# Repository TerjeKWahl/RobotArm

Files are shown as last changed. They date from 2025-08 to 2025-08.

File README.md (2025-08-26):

# RobotArm

Humanoid robot arm with 6 DoF and a gripper, built mostly in Lego, controllable from VR and (todo) with AI to make it autonomous.

This repository contains the following project parts in these folders:
- `EmbeddedControllers` Robot arm embedded controllers
  - `ControllerLowerArm` Lego Technic Hub 1 controller (lower arm) using Pybricks
  - `ControllerShoulder` Lego Technic Hub 2 controller (shoulder) using Pybricks
  - `ControllerGripper` Controller for the gripper using Arduino
- `RobotArmController` Main controller program in Python, executed on a PC to 
  - control the robot arm using inverse kinematics,
  - communicate with the Lego Technic Hubs and Arduino controllers,
  - communicate with any connected VR app,
  - (todo) gather images from vision camera,
  - (todo) do AI raw data collection and
  - (todo) do AI inference
- `VR` Meta Quest 3 VR app to remote control the robot arm and (todo) record AI training data
- `AI` TODO: AI stuff: Training and inference
- `Mechanics` 3D files for custom made mechanical parts
  - `GripperForMicroServo` 3D files for robot gripper
  - `LegoTechnicHubWireInset` 3D file for modifying Lego Technic Hub to be driven by a power adapter in stead of batteries
  - `VrGripper` 3D file for the virtual representation of the gripper in the VR app

These components communicate using well defined communication APIs. Please see the `Docs` folder for more information.

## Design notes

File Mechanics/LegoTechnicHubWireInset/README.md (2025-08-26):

# Lego Technic Hub wire inset

Based on the "9V Battery Adapter for Lego Powered Up/Control+ Technic Hub"
by 2GodBDGlory (Cole Johnstone). The original work can be found here: 
https://www.thingiverse.com/thing:6434892

Modified using FreeCAD to be able to hold 0.7 mm wires over the battery contact points, so that a 9V power adapter can be used to continuously power the Lego Technic Hub.

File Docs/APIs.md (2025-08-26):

# APIs used for communicating between components

The following APIs are used:
- API for communication between PC application and Lego Technic Hub 1 (lower arm) or Lego Technic 
  Hub 2 (shoulder) or Arduino (gripper)
- API for communication between PC application and VR app

## API for communication between PC application and Lego Technic Hub 1 or 2, and Arduino:

We want to keep payloads short when communication with Lego Hubs, because of Bluetooth packet limitations (source:
https://github.com/pybricks/technical-info/blob/master/pybricks-ble-broadcast-observe.md). Because of this, a
proprietary binary communication protocol is used. Angles are in degrees. 
The numbering in the two lists below represent byte numbers.

### Message from PC to Lego Technic Hub 1 or 2 or Arduino (the same data is sent to all):

1.  Prefix "T"
2.  Prefix "W"
3.  API version, 1
4.  int8, requested movement mode:  
    - 1 = move all joints as fast as possible (for continuous tracking)
    - 2 = move to target with smooth acceleration and deceleration (run to target)
    - 3 = calibration mode
    - 4 = return to standard/zero angles, and exit
5.  int8, desired angle for gripper
6.  int8, desired angle for wrist  
7.  int8, desired angle for underarm 
8.  int8, desired angle for elbow   
9.  int8, desired angle for overarm  
10. int8, desired angle for shoulder_out  
11. int8, desired angle for shoulder_forward 
12. int8, last known angle for gripper
13. int8, last known angle for wrist  
14. int8, last known angle for underarm 
15. int8, last known angle for elbow   
16. int8, last known angle for overarm  
17. int8, last known angle for shoulder_out  
18. int8, last known angle for shoulder_forward 

### Message from Lego Technic Hub 1 or 2 or Arduino to PC:

1.  Prefix "T"
2.  Prefix "W"
3.  API version, 1
4.  int8, information source:  
    - 10 = Lego Technic Hub 1 (lower arm), ignore shoulder and gripper joint values
    - 11 = Lego Technic Hub 2 (shoulder), ignore lower arm and gripper joint values
    - 12 = Arduino (gripper), ignore shoulder and lower arm joint values
5.  int8, error code - 0 means no error
6.  int8, current angle for gripper (or -128 if unknown)
7.  int8, current angle for wrist (or -128 if unknown)
8.  int8, current angle for underarm (or -128 if unknown)
9.  int8, current angle for elbow (or -128 if unknown)
10. int8, current angle for overarm (or -128 if unknown)
11. int8, current angle for shoulder_out (or -128 if unknown)
12. int8, current angle for shoulder_forward (or -128 if unknown)

## API for communication between PC application and VR app

To make communication efficient on a LAN, we use UDP packets and make sure the payload is short enough 
to fit within one WiFi/Ethernet UDP package (around 1400 bytes).

When talking about position and rotation in messages to and from the VR app, we use the VR/Unity coordinate
system (x-right, y-up, z-forward), and not the robot arm's coordinate system (x-forward, y-left, z-up).

VR app should send a UDP package to the PC every second frame (around 30-36 times per second).

The PC should send a UDP package to the VR app around 30-50 times per second.

16 bit numbers are sent big-endian (MSB first, LSB last). Distances are in mm. Angles are in degrees. 

### Message from VR to PC:

1.  Prefix "T"
2.  Prefix "K"
3.  Prefix "W"
4.  API version, 1
5.  int8, information source:  
    - 20 = VR app
6.  int8, desired gripper angle, in degrees
7.  int8, desired recording status: 0=off, 1=on
8.  (Reserved for future use, extra byte to avoid bugs due to struct packing.)
9.  Bytes number 9 to 136: 16 double floating point numbers, representing the 4 x 4 matrix 
    describing the position and rotation of the VR gripper.
    16 doubles * 8 bytes/double = 128 bytes.
    The numbers are row first, so the first 4 numbers represent the first row, etc.

### Message from PC to VR:

1.  Prefix "T"
2.  Prefix "K"
3.  Prefix "W"
4.  API version, 1
5.  int8, information source:  
    - 21 = PC app
6.  (Reserved for future use, extra byte to avoid bugs due to struct packing.)
7.  (Reserved for future use, extra byte to avoid bugs due to struct packing.)
8.  (Reserved for future use, extra byte to avoid bugs due to struct packing.)
9.  Bytes number 9 to 136: 16 double floating point numbers, representing the 4 x 4 matrix 
    describing the last known position and rotation of the physical robot arm's gripper.
    16 doubles * 8 bytes/double = 128 bytes.
    The numbers are row first, so the first 4 numbers represent the first row, etc.

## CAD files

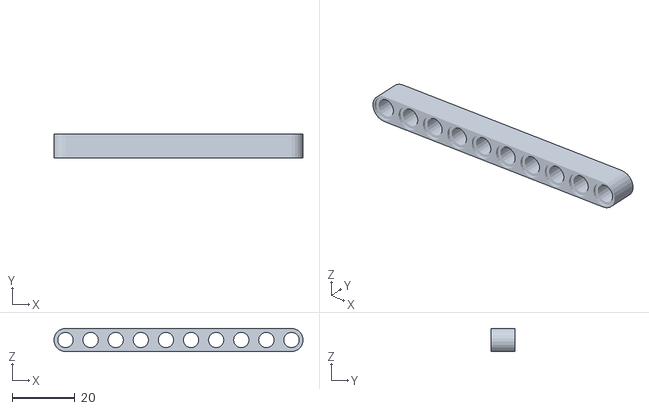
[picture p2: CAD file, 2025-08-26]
Mechanics/GripperForMicroServo/10M_Beam_Lego.stl
79.3 x 7.80 x 7.40

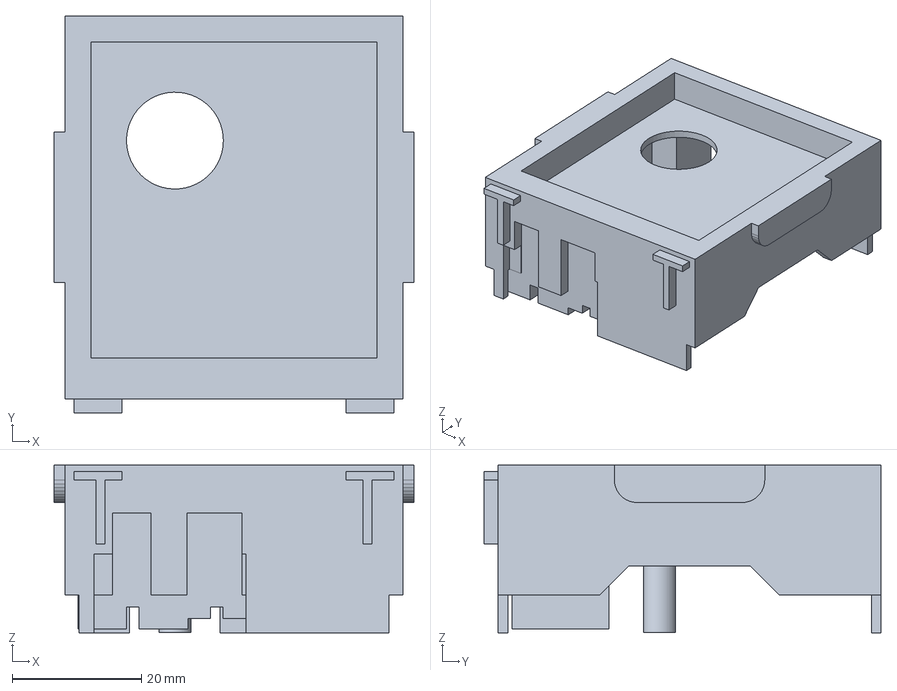
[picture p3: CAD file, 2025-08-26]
Mechanics/LegoTechnicHubWireInset/Lego Technic Hub wire inset.FCStd
55.7 x 61.5 x 26.0 mm

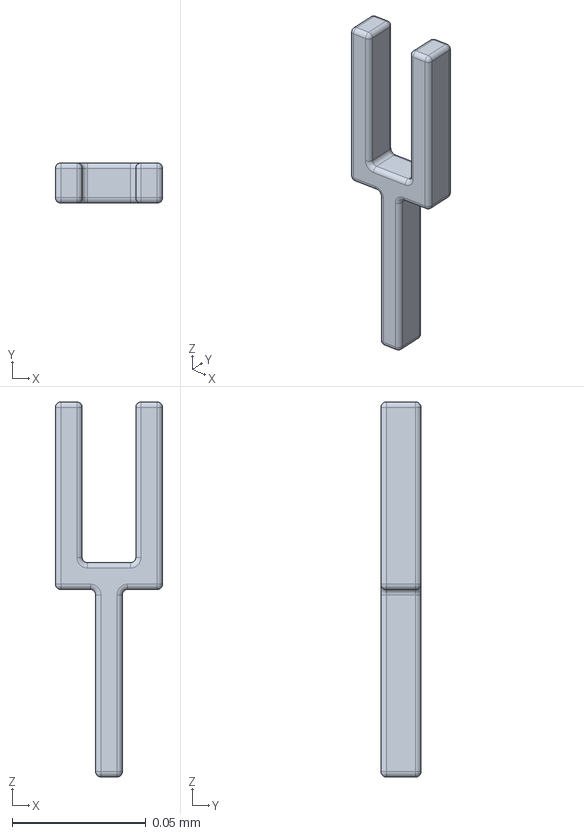
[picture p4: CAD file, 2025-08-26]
Mechanics/VrGripper/VrGripper.FCStd
0.04 x 0.015 x 0.14 mm

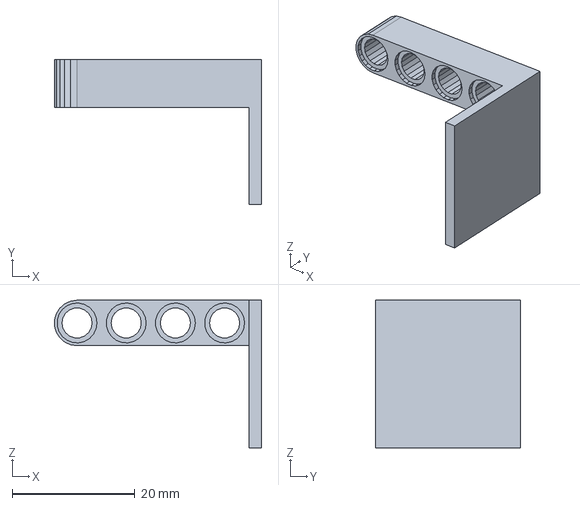
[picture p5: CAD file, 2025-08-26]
Mechanics/GripperForMicroServo/GripperForMicroServo.FCStd
33.7 x 23.6 x 24.0 mm

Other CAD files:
VR/RobotArmRemoteController/Assets/VrGripper.obj
Mechanics/LegoTechnicHubWireInset/Lego Technic Hub wire inset - 1.1.step
Mechanics/LegoTechnicHubWireInset/9V_Powered_Up_Adapter_v3.stl
Mechanics/VrGripper/VrGripper.obj

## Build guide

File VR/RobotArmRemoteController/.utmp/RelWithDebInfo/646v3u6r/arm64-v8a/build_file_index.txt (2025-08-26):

C:\dev\RobotArm\VR\RobotArmRemoteController\Library\Bee\Android\Prj\IL2CPP\Gradle\unityLibrary\src\main\cpp\CMakeLists.txt
C:\dev\RobotArm\VR\RobotArmRemoteController\Library\Bee\Android\Prj\IL2CPP\Gradle\unityLibrary\src\main\cpp\GameActivity\CMakeLists.txt

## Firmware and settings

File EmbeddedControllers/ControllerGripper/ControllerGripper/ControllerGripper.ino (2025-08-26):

/**
 * Controlling a servo using an Arduino Uno R4 WiFi. 
 * 
 * Servo used: 
 * Geekservo 2KG Mini Servo 360 Degree
 * ------------
 * Weight: 20g
 * Operating voltage: 4.8V - 6.0V
 * Operating speed (at no load) 0.14±0.01sec/60° 0.12±0.01sec/60°
 * Running current (at no load) 70±20mA 90±20mA
 * Stall torque (at locked) 1.8±0.2kg-cm 2±0.2kg-cm
 * Stall current (at locked) 0.8±0.1A 0.9±0.1A
 * Neutral position:1500μsec
 * Dead band width: ≤4μsec
 * Rotating direction: counter Clockwise (1500→500μsec)
 * Pulse width range: 500→2500 μsec
 * Maximum travel 360°(500→2500 μsec)
 *
 * Wiring:
 * Brown: GND
 * Red: VCC (4.8 ~ 6.6v)
 * Orange: PWM Signal
 */

#include "Arduino_LED_Matrix.h"
#include <Servo.h>
#include <WiFiS3.h>
#include "WifiSecrets.h"    // Please enter your sensitive data into WifiSecrets.h, by defining SECRET_SSID and SECRET_PASS there.
#include "Configuration.h"
#include "RobotMessageManager.h"

const int16_t SERVO_PIN = 9;
const uint32_t MAX_WAIT_TIME_FOR_SERIAL_MS = 3000; // Maximum wait time for serial connection to start working on startup, in milliseconds

Servo gripperServo; 

int wifiStatus = WL_IDLE_STATUS;
char ssid[] = SECRET_SSID;  // your network SSID (name)
char pass[] = SECRET_PASS;  // your network password (use for WPA, or use as key for WEP)
char receiveBuffer[256]; //buffer to hold incoming packet
char sendBuffer[256] = "TKW"; // a string to send back
WiFiUDP udp;

ArduinoLEDMatrix matrix;
uint32_t frame[] = { 0x00000000, 0x00000000, 0x00000000 }; // 1-bit display buffer for the 12 x 8 pixel display


void setup() 
{
    Serial.begin(115200);

    matrix.begin();
    matrix.loadFrame(LEDMATRIX_CHIP); // Boot screen
    
    gripperServo.attach(SERVO_PIN);
    gripperServo.writeMicroseconds(getServoUsFromDegrees(GRIPPER_ANGLE_MAX_DEG));

    while (!Serial && (millis() < MAX_WAIT_TIME_FOR_SERIAL_MS)) {
        ; // Wait for serial port to connect.
    }
    while (millis() < MAX_WAIT_TIME_FOR_SERIAL_MS) 
    {
        delay(10); // Give some time for the serial connection to stabilize, if it was plugged in.
    }

    Serial.println("\nControllerGripper started!");

    matrix.loadFrame(LEDMATRIX_CLOUD_WIFI);
    connectToWifi();

    Serial.println("\nStarting connection to server...");
    udp.begin(ARDUINO_UDP_PORT);

    Serial.println("Setup complete, ready to control the gripper.");
    matrix.loadFrame(LEDMATRIX_HEART_BIG);
    delay(500);
    matrix.loadFrame(LEDMATRIX_EMOJI_HAPPY);
    delay(500);
}

  
void loop() 
{

    while(true)
    {
        // Demo mode
        uint32_t demoDurationWantedMs = 0; //20000; // Duration of demo mode before going into normal remote control function. Set to 0 to skip demo mode.
        uint32_t currentTimeMs = millis();
        uint32_t demoStartMs = currentTimeMs;
        int16_t servoPositionDegrees = 0;
        if (demoDurationWantedMs > 0)
        {
            Serial.println("Starting demo mode");
            while (currentTimeMs - demoStartMs < demoDurationWantedMs) {
                uint32_t timeInPeriod = (currentTimeMs - demoStartMs) % 10000; // 10 seconds cycle

                if (timeInPeriod < 2000) 
                {
                    servoPositionDegrees = map(timeInPeriod, 0, 2000, GRIPPER_ANGLE_MIN_DEG, GRIPPER_ANGLE_MAX_DEG);
                } 
                else if (timeInPeriod < 4000) 
                {
                    servoPositionDegrees = map(timeInPeriod, 2000, 4000, GRIPPER_ANGLE_MAX_DEG, GRIPPER_ANGLE_MIN_DEG);
                } 
                else if (timeInPeriod < 5000) 
                {
                    servoPositionDegrees = GRIPPER_ANGLE_MIN_DEG;
                } 
                else if (timeInPeriod < 6000) 
                {
                    servoPositionDegrees = map(timeInPeriod, 5000, 6000, GRIPPER_ANGLE_MIN_DEG, GRIPPER_ANGLE_MAX_DEG);
                } 
                else if (timeInPeriod < 7000) 
                {
                    servoPositionDegrees = map(timeInPeriod, 6000, 7000, GRIPPER_ANGLE_MAX_DEG, GRIPPER_ANGLE_MIN_DEG);
                } 
                else if (timeInPeriod < 7500) 
                {
                    servoPositionDegrees = map(timeInPeriod, 7000, 7500, GRIPPER_ANGLE_MIN_DEG, GRIPPER_ANGLE_MAX_DEG);
                } 
                else if (timeInPeriod < 8000) 
                {
                    servoPositionDegrees = map(timeInPeriod, 7500, 8000, GRIPPER_ANGLE_MAX_DEG, GRIPPER_ANGLE_MIN_DEG);
                } 
                else 
                {
                    servoPositionDegrees = GRIPPER_ANGLE_MIN_DEG;
                }

                moveGripper(servoPositionDegrees);

                currentTimeMs = millis(); // Update current time for next iteration of the while loop
            }
            Serial.println("Demo mode finished, entering normal operation mode.");
        }


        // Normal operation
        while(true) // Outer loop to handle errors and reconnects
        {
            int16_t servoPositionDegrees = GRIPPER_ANGLE_MAX_DEG; // Start with fully opened gripper
            moveGripper(servoPositionDegrees);
            int32_t lastSendTimeMs = 0;

            while(true) // Inner loop to handle incoming UDP messages and send updates
            { 
                // Check if WiFi is still connected (WiFi.status() == WL_CONNECTED)
                if (WiFi.status() != WL_CONNECTED) {
                    Serial.println("WiFi disconnected!");
                    break; // Exit the inner loop to reconnect
                }

                // Update the gripper position based on any incoming UDP messages
                int packetSize = udp.parsePacket();
                if (packetSize) 
                {
                    uint8_t receiveBuffer[REC_MSG_LENGTH];
                    if (packetSize > REC_MSG_LENGTH) 
                    {
                        Serial.println("Packet size exceeds buffer size. Ignoring it.");
                        udp.flush();
                    }
                    else
                    {
                        int len = udp.read(receiveBuffer, REC_MSG_LENGTH);
                        if (len == 0) 
                        {
                            Serial.println("Failed to read UDP packet.");
                            break; // Exit the inner loop to reconnect
                        }
                        // Parse the incoming message
                        bool isSuccessful = false;
                        MessageFromPcToController incomingMessage = parseMessageFromPcToController(receiveBuffer, len, &isSuccessful);
                        if (!isSuccessful) 
                        {
                            Serial.println("Failed to parse incoming message.");
                            break; // Exit the inner loop to reconnect
                        }
                        servoPositionDegrees = incomingMessage.desiredAngles.gripper;
                        if (incomingMessage.movementMode == RETURN_TO_ZERO) 
                        {
                            servoPositionDegrees = GRIPPER_ANGLE_MAX_DEG; // Full opening of the gripper is the default position ("zero")
                        }
                        moveGripper(servoPositionDegrees);

                        /*
                        // Debug output is slow (synchronous) and the lines below causes visible lag for the gripper, so only print if you need to debug
                        Serial.print("Received packet of size ");
                        Serial.print(packetSize);
                        Serial.print(" from ");
                        IPAddress remoteIp = udp.remoteIP();
                        Serial.print(remoteIp);
                        Serial.print(", port ");
                        Serial.println(udp.remotePort());
                        Serial.print("New desired gripper angle: ");
                        Serial.println(servoPositionDegrees);
                        */
                    }
                }


                // Send UDP message to the PC every SEND_PERIOD_MS milliseconds
                uint32_t currentTimeMs = millis();
                if (currentTimeMs - lastSendTimeMs >= SEND_PERIOD_MS) {
                    lastSendTimeMs = currentTimeMs;
                    udp.beginPacket(PC_IP_ADDRESS, ARDUINO_UDP_PORT);
                    uint8_t sendBuffer[SEND_MSG_LENGTH];
                    createMessageFromControllerToPc(servoPositionDegrees, sendBuffer);
                    udp.write(sendBuffer, SEND_MSG_LENGTH);
                    int16_t isSentSuccessfully = udp.endPacket();
                    if (!isSentSuccessfully) {
                        Serial.println("Failed to send UDP packet!");
                        break; // Exit the inner loop to reconnect
                    }
                }
            }

            // Disconnect and reconnect to WiFi
            Serial.println("Disconnecting from WiFi, and attempting reconnect...");
            udp.flush();
            udp.stop();
            WiFi.end();
            connectToWifi();
        }


    }
}


/**
 * Moves the gripper servo to the specified position and updates the LED matrix display.
 * 
 * @param targetDegrees: Target position for the gripper servo in degrees
 */
void moveGripper(int16_t targetDegrees) {
    gripperServo.writeMicroseconds(getServoUsFromDegrees(targetDegrees));
    updateFrame(frame, targetDegrees);
    matrix.loadFrame(frame);
}


/**
 * Updates the frame that represents the 1-bit display buffer for the 12 x 8 pixel display.
 * Lights up from 0 to 12 pixels on the first two rows, depending on the servoPositionDegrees that
 * is from GRIPPER_ANGLE_MIN_DEG to GRIPPER_ANGLE_MAX_DEG degrees.
 */
void updateFrame(uint32_t *frame, int servoPositionDegrees) 
{
    // Check for valid servo position by clipping it to the valid range
    if (servoPositionDegrees < GRIPPER_ANGLE_MIN_DEG) 
    {
        servoPositionDegrees = GRIPPER_ANGLE_MIN_DEG;
    } 
    else if (servoPositionDegrees > GRIPPER_ANGLE_MAX_DEG) 
    {
        servoPositionDegrees = GRIPPER_ANGLE_MAX_DEG;
    }
    // Could do some error checking here on the frame buffer, but hey this is a hobby project.

    // Clear the frame first (reset all bits except type "TW" in the middle of the display))
    frame[0] = 0b00000000000000000000000001110100;
    frame[1] = 0b01000010010101000010001010000010;
    frame[2] = 0b00101000000000000000000000000000;
    
    // Map servo position to number of pixels (0-12). 
    int numPixels = map(servoPositionDegrees, GRIPPER_ANGLE_MAX_DEG, GRIPPER_ANGLE_MIN_DEG, 0, 12);

    // Set pixels in first two rows
    for (int bitPosition = 0; bitPosition < numPixels; bitPosition++) {
        // Set pixel in first row (bits 31-20)
        frame[0] |= (1UL << (31 - bitPosition));
        // Set pixel in second row (bits 19-8)
        frame[0] |= (1UL << (19 - bitPosition));
    }
}


void connectToWifi() 
{
    Serial.println("Connecting to WiFi network...");

    // Check for the presence of the WiFi module:
    if (WiFi.status() == WL_NO_MODULE) {
        Serial.println("Communication with WiFi module failed!");
        // Don't continue
        while (true);
    }

    String fv = WiFi.firmwareVersion();
    if (fv < WIFI_FIRMWARE_LATEST_VERSION) {
        Serial.println("(Please consider upgrading the WiFi module firmware.)");
    }

    // Attempt to connect to WiFi network:
    Serial.print("Attempting to connect to SSID: ");
    Serial.println(ssid);
    // Connect to WPA/WPA2 network. Change this line if using open or WEP network:
    wifiStatus = WiFi.begin(ssid, pass);
    // wait up to 10 seconds for connection:
    int secondsWaited = 0;
    while (wifiStatus != WL_CONNECTED && secondsWaited < 20) 
    {
        Serial.println("Waiting for connection...");
        delay(1000);
        wifiStatus = WiFi.status();
        secondsWaited++;
    }
    IPAddress ip = WiFi.localIP();
    while ((uint32_t)ip == 0 && secondsWaited < 20) 
    {
        Serial.println("Waiting for IP address...");
        delay(1000);
        ip = WiFi.localIP();
        secondsWaited++;
    }
    Serial.println("Connected to WiFi!");
    printWifiStatus();
}


void printWifiStatus() {
    // print the SSID of the network you're attached to:
    Serial.print("SSID: ");
    Serial.println(WiFi.SSID());

    // print your board's IP address:
    IPAddress ip = WiFi.localIP();
    Serial.print("IP Address: ");
    Serial.println(ip);

    // print the received signal strength:
    long rssi = WiFi.RSSI();
    Serial.print("signal strength (RSSI):");
    Serial.print(rssi);
    Serial.println(" dBm");
}


/**
 * Converts servo position in degrees to microseconds for PWM control.
 * Standard servo control uses pulse widths between 500-2500 microseconds.
 * 
 * This function is customized to fit with the servo and physical robot arm being used,
 * to match the minimum and maximum angles to the physical robot arm.
 * 
 * @param degrees: Servo position in degrees
 * @return: Pulse width in microseconds
 */
uint16_t getServoUsFromDegrees(int16_t degrees) {
    // Constrain degrees to valid servo range (0-180)
    if (degrees < GRIPPER_ANGLE_MIN_DEG) {
        degrees = GRIPPER_ANGLE_MIN_DEG;
    } else if (degrees > GRIPPER_ANGLE_MAX_DEG) {
        degrees = GRIPPER_ANGLE_MAX_DEG;
    }

    // Map degrees (GRIPPER_ANGLE_MIN_DEG-GRIPPER_ANGLE_MAX_DEG) to microseconds
    const int16_t US_MIN = 1500 + 25; // Don't squeeze too tightly
    const int16_t US_MAX = 1750; // 1500 + 5.55 per degree. So for 45 degrees it is 1500+250 = 1750
    const int16_t SPAN = GRIPPER_ANGLE_MAX_DEG - GRIPPER_ANGLE_MIN_DEG;
    return US_MIN + ((uint32_t)degrees * (US_MAX - US_MIN)) / SPAN;
}

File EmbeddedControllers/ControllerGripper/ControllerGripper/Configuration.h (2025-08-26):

#include <stdint.h>
#include "IPAddress.h"

// Please make a DHCP reservation on your router for this device and the PC, so that they 
// always get the same IP address that can be used to control the gripper.
const IPAddress PC_IP_ADDRESS = IPAddress( 192, 168, 0, 43 ); // IP address of the PC that controls the gripper
const uint16_t ARDUINO_UDP_PORT = 7507; // Port for UDP communication between Arduino and PC (both sending and receiving)

const uint8_t GRIPPER_ANGLE_MIN_DEG = 0;
const uint8_t GRIPPER_ANGLE_MAX_DEG = 45;

const int16_t SEND_PERIOD_MS = 100; // How often to send current gripper angle to the PC app

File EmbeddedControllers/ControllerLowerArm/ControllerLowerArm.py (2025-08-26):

"""
Controls the lower 4 axis on a robot arm (wrist, underarm twist, elbow, overarm twist), 
and communicates with a PC app.
Built using Pybricks (see pybricks.com for more info).
"""

from pybricks.hubs import TechnicHub
from pybricks.pupdevices import Motor
from pybricks.parameters import Button, Color, Direction, Port, Side, Stop
from pybricks.tools import wait, StopWatch
from usys import stdin, stdout
from uselect import poll, POLLIN
from micropython import kbd_intr
from RobotMessageBuilderEmbedded import JointAngles, MessageFromPCToController, \
     parse_message_from_PC_to_controller, create_message_from_controller_to_PC, \
     INFORMATION_SOURCE_HUB_1, REC_MSG_LENGTH, \
     MOVEMENT_MODE_MOVE_FAST, MOVEMENT_MODE_RUN_TO_TARGET, \
     MOVEMENT_MODE_CALIBRATION, MOVEMENT_MODE_RETURN_TO_ZERO_AND_EXIT

PRINT_DEBUG_INFO = False # Set to True to enable debug messages via printing to stdout. This will interfere with Bluetooth communication that also uses stdout!
SEND_PERIOD_MS = 20 # How often to send current angles to the PC app

is_continuous_tracking = False
hub = TechnicHub()
stopwatch = StopWatch()
stopwatch.resume()
receive_buffer = bytearray(REC_MSG_LENGTH)

# Motor definitions, including gearing ratios:
wrist    = a = Motor(Port.A, positive_direction=Direction.CLOCKWISE,        reset_angle=False, gears=[[20, 12], [ 1, 12], [12, 28]]) # Wrist up/down (as seen when right thumb is up)
underarm = b = Motor(Port.B, positive_direction=Direction.CLOCKWISE       , reset_angle=False, gears=[[ 8, 24], [12, 20], [ 8, 28]]) # Underarm twist
elbow    = c = Motor(Port.C, positive_direction=Direction.COUNTERCLOCKWISE, reset_angle=False, gears=[[ 1, 24], [20, 28]]) # Elbow
overarm  = d = Motor(Port.D, positive_direction=Direction.COUNTERCLOCKWISE, reset_angle=False, gears=[[ 8, 24], [12, 60]]) # Overarm twist

last_known_angles = JointAngles(set_all_unknown = True)
last_send_time = 0
last_receive_time = 0
desired_angle_wrist = 0
desired_angle_underarm = 0


def print_debug(string):
    if PRINT_DEBUG_INFO:
        print(string)



def get_compensations_for_angles(last_known_angles: JointAngles):
    """
    Calculates the compensations needed for the wrist and underarm angles based on the last known angles.
    """
    # Calculate the compensation of underarm due to elbow angle
    underarm_compensation = last_known_angles.elbow * 0.4 # (28/12) * (12/20) * (8/28)

    # Calculate the compensation of wrist due to underarm and elbow angles
    wrist_compensation_due_to_underarm = last_known_angles.underarm * 0.428571429 # (12/28)
    wrist_compensation_due_to_elbow = last_known_angles.elbow # * (28/12) * (12/28), which is 1
    wrist_compensation = wrist_compensation_due_to_underarm + wrist_compensation_due_to_elbow

    return wrist_compensation, underarm_compensation



def send_current_angles_to_pc(last_known_angles: JointAngles):
    """
    Reads current motor positions and sends them to PC via stdout.
    Updates the relevant values in last_known_angles.
    """
    # Update known angles from motor positions
    known_angle_wrist = wrist.angle()
    known_angle_underarm = underarm.angle()
    known_angle_elbow = elbow.angle()
    known_angle_overarm = overarm.angle()
    last_known_angles.wrist = known_angle_wrist
    last_known_angles.underarm = known_angle_underarm
    last_known_angles.elbow = known_angle_elbow
    last_known_angles.overarm = known_angle_overarm

    # Create JointAngles with only lower arm angles known
    # Subtract compensation of wrist and underarm to report in the same way the desired 
    # angle is used, to avoid the robot arm being unstable (wiggling)
    wrist_compensation, underarm_compensation = get_compensations_for_angles(last_known_angles)
    current_angles = JointAngles(set_all_unknown=True)
    current_angles.wrist = known_angle_wrist - int(wrist_compensation+0.5)
    current_angles.underarm = known_angle_underarm - int(underarm_compensation+0.5)
    current_angles.elbow = known_angle_elbow
    current_angles.overarm = known_angle_overarm

    # Create and send reply message
    reply_message = create_message_from_controller_to_PC(INFORMATION_SOURCE_HUB_1, current_angles)
    stdout.buffer.write(reply_message)
    stdout.flush()  # Ensure the message is sent immediately



def track_compensated_angles(desired_angle_wrist, desired_angle_underarm, last_known_angles : JointAngles):
    """
    Adjusts the wrist and underarm motor targets based on the desired angles and the last known angles.
    Assumes that the last known angles are just read and therefore relatively accurate.
    Note: This function does not control the elbow and overarm motors.
    """
    wrist_compensation, underarm_compensation = get_compensations_for_angles(last_known_angles)

    # Track the compensated angles of the motors
    wrist.track_target(desired_angle_wrist + wrist_compensation)
    underarm.track_target(desired_angle_underarm + underarm_compensation)



print_debug("Control limits (speed, acceleration, torque):")
print_debug(a.control.limits())
print_debug(b.control.limits())
print_debug(c.control.limits())
print_debug(d.control.limits())

print_debug("Control target tolerances (speed, position):")
print_debug(a.control.target_tolerances())
print_debug(b.control.target_tolerances())
print_debug(c.control.target_tolerances())
print_debug(d.control.target_tolerances())

# Registering stdin for polling. This allows us to wait for incoming data without blocking:
kbd_intr(-1) # Disables keyboard interupt on stdin
stdin_event_monitor = poll()
stdin_event_monitor.register(stdin, POLLIN)

# Reset position:
hub.light.blink(Color.ORANGE,[600,200]) # Orange blinking indicates calibrating or resetting to zero angles
a.run_target(1500, 0, then=Stop.HOLD, wait=True)
b.run_target(1500, 0, then=Stop.HOLD, wait=True)
c.run_target(1500, 0, then=Stop.HOLD, wait=True)
d.run_target(1500, 0, then=Stop.HOLD, wait=True)
#a.reset_angle(0)
#b.reset_angle(0)
#c.reset_angle(0)
#d.reset_angle(0)
#wait(2000)
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

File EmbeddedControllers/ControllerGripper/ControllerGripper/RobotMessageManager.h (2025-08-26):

#ifndef ROBOT_MESSAGE_MANAGER_H
#define ROBOT_MESSAGE_MANAGER_H

#include <stdint.h>
#include <stdbool.h>
#include <string.h>
#include <stdio.h>

#define REC_MSG_LENGTH 18
#define SEND_MSG_LENGTH 12


typedef enum {
    MOVE_FAST = 1,       // Move all joints as fast as possible (for continuous tracking)
    RUN_TO_TARGET = 2,   // Move to target with smooth acceleration and deceleration (run to target)
    CALIBRATION = 3,     // Calibration mode
    RETURN_TO_ZERO = 4   // Return to standard/zero angles, and exit
} MovementMode;


typedef enum {
    ARDUINO_GRIPPER = 12,       // Arduino (gripper)
} InformationSource;


typedef struct {
    int8_t gripper;
    int8_t wrist;
    int8_t underarm;
    int8_t elbow;
    int8_t overarm;
    int8_t shoulderOut;
    int8_t shoulderForward;
} JointAngles;


typedef struct {
    char prefixT;
    char prefixW;
    int8_t apiVersion;
    int8_t movementMode;
    JointAngles desiredAngles;
    JointAngles lastKnownAngles;
} MessageFromPcToController;


typedef struct {
    char prefixT;
    char prefixW;
    int8_t apiVersion;
    int8_t informationSource;
    int8_t errorCode;
    JointAngles currentAngles;
} MessageFromControllerToPC;


/**
 * Parses a message from the PC to the robot arm controller.
 * 
 * @param data: The byte array representing the message
 * @param dataLength: Length of the data array
 * @param isSuccessful: Out parameter - false if message is not as expected, true if valid
 * @return: MessageFromPcToController struct with parsed data
 */
MessageFromPcToController parseMessageFromPcToController(const uint8_t* data, size_t dataLength, bool* isSuccessful);


/**
 * Creates a binary message from controller to PC.
 * For now, the errorCode is always 0 (no error).
 *
 * @param currentGripperAngleDeg: Current gripper angle, in degrees
 * @param output: Output buffer to write the message (must be at least SEND_MSG_LENGTH bytes)
 * @return: Number of bytes written to output buffer
 */
size_t createMessageFromControllerToPc(int8_t currentGripperAngleDeg, uint8_t* output);


#endif // ROBOT_MESSAGE_MANAGER_H

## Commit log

2025-07-21 Initial proof of concept code for robot lower arm.
2025-07-21 Version 1 of Lego Technic Hub wire inset, to power it continuously from a power adapter in stead of batteries.
    [9V_Powered_Up_Adapter_v3.stl, Lego Technic Hub wire inset - 1.0.step, Lego Technic Hub wire inset.FCStd]
2025-07-21 Added program to test inverse kinematics with the Robotics Toolbox for Python library.
2025-07-22 Input real robot arm dimensions into the robot kinematics model. Added priorites so that hand rotation around the Y axis is allowed to be different from intended pose.
2025-07-23 Added first version of Arduino program, that is a proof of concept dummy program for controlling a servo (the robot gripper).
2025-07-24 Arduino WiFi connection now works (but is not used yet).
2025-07-27 Imroved lower arm controller angle limits.
2025-07-27 Made the lower arm controller ready to receive and follow messages from PC
2025-07-27 Added joint limits to IK
2025-07-28 Created a chain of movements for the robot, simulated.
2025-07-31 Robot arm is waiving. Bug fixes.
2025-08-01 Adjusted position of VR gripper
2025-08-01 VR app now calculates and displays updated offset of position and rotation for the virtual gripper.
2025-08-02 Lego controllers now update PC with their current angles.
2025-08-03 Refactoring to avoid potential bug
    [ControllerLowerArm.py, ControllerShoulder.py]
2025-08-03 Movement mode is now supported (except calibration, which is done more manually for now).
2025-08-03 Implemented UdpManager for sending and receiving messages between PC app and VR device (and later also Arduino).
2025-08-04 Created a virtual gripper in 3D for (temporary) use in the VR app
    [VrGripper.FCStd, VrGripper.obj]
2025-08-04 UPD messages are now flowing from the VR app to the PC
2025-08-06 Updated Lego Technic Hub wire inset, to fix problem with crashing with battery guide, and also fitting other version of battery box with lid that can be taken off without screws.
    [Lego Technic Hub wire inset - 1.0.step, Lego Technic Hub wire inset - 1.1.step, Lego Technic Hub wire inset.FCStd]
2025-08-07 Fixed reversed underarm rotation direction
    [ControllerLowerArm.py]
2025-08-12 Fixed bug with IK last known position being given in degrees in stead of in radians. Added a 7th joint (as a virtual 2nd wrist joint) to stabilize IK calculations.
    [ControllerLowerArm.py]
2025-08-12 More liberal joint limits on PC than on Lego hubs, gives more stable remote control via VR.
2025-08-13 Adjusted joint angle limits, and implemented function to avoid crashing into table/desk or robot torso.
    [ControllerLowerArm.py, ControllerShoulder.py]
2025-08-17 Modified gear ratios after rebuilding underarm.
2025-08-17 Implemented compensated angles for wrist and underarm, due to rotation of elbow (and underarm for the wrist), when in continuous tracking mode. Fixed wrong gearing ratio for wrist.
    [ControllerLowerArm.py]
2025-08-18 Subtract compensation of wrist and underarm to report in the same way the desired angle is used, to avoid the robot arm being unstable (wiggling).
    [ControllerLowerArm.py]
2025-08-18 Started making 3D CAD file for gripper
    [10M_Beam_Lego.stl, GripperForMicroServo.FCStd]
2025-08-19 Created RobotMessageManager for the Arduino controller
    [Configuration.h]
2025-08-19 Adjusted the gripper span (min and max opening/angles)
    [Configuration.h]
2025-08-19 Implemented Arduino handling sending and receiving UDP messages
    [Configuration.h]
2025-08-19 Working remote control of the gripper from the PC in demo mode
2025-08-20 Clean up. Added reading controller trigger and converting it to desired gripper angle. Added isRecording true/false, controlled by A button.
2025-08-20 Added desired gripper angle and recording status to the messages from VR to PC. Fixed euler rotation display text.
2025-08-20 Updated 3D gripper CAD file, but it might never be used because I found an alternative method using Lego bricks and a Lego compatible servo
    [GripperForMicroServo.FCStd]
2025-08-20 PC app now sends gripper angle from the VR app to the Arduino
2025-08-20 Optimized gripper response time in the Arduino code
2025-08-21 Switched wrist from left/right to up/down, to make it easier to pick things up from a table
